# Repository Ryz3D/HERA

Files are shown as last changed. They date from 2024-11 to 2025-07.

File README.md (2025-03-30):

# **HERA**: _**H**opefully **E**lectronics **R**unning **A**utomatically_

A slightly less simple CPU than the [SPEAR](https:#github.com/Ryz3D/SPEAR). It is way more powerful due to:

- Significantly more control lines, thus more instructions
- An extra `C` register
- Direct read and write access to all registers
- Jump and branches as individual instructions (SPEAR solution was creative, but tedious)
- A 16-bit bus (i.e. jump in single cycle)
- 16-bit registers and ALU
- RAM size increased from 256 bytes to 128 KiB
- Additional NOR operation
- Multiple flags (carry out, zero, negative) in a proper status register
- Far better input/output capabilities
- Instructions without literal value fit into one byte

## Features

- Full 16-bit architecture
  - 16-bit addressing for ROM and RAM (ROM: 64 KiB, RAM: 128 KiB)
    - Two RAM chips for direct 16-bit access
  - 16-bit bus, registers and ALU
- Usable digital I/O
  - 256 input ports (16-bit)
  - 256 output ports (16-bit), can be extended at expense of RAM size

## Technical details

### Instructions

The upper 4 bits of any instruction represent control lines for writing to the internal bus (everything but `STAT` uses 16-bit values):
| Upper nibble | Name | Description |
| --- | --- | --- |
| 0 | `LIT` | Literal value |
| 1 | `A` | A register |
| 2 | `B` | B register |
| 3 | `C` | C register |
| 4 | `RAM` | RAM |
| 5 | `RAM_P` | RAM pointer register |
| 6 | `PC` | Program counter register |
| 7 | `STAT`  | Status register (8-bit)  |
| 8 | - | - |
| 9 | - | - |
| A | `ADD` | Add (`A + B`) |
| B | `COM` | Two's complement (`-A`)  |
| C | `NOR` | NOR (`~(A \| B)`) |
| D | - | - |
| E | - | - |
| F | - | - |

If a literal is selected to be written to the bus (upper nibble is 0x0), it is read from the two bytes after the instruction in big-endian format.

The lower 4 bits represent control lines for reading from the internal bus:
| Lower nibble | Name | Description |
| --- | --- | --- |
| 0 | `VOID` | Ignore value |
| 1 | `A` | A register |
| 2 | `B` | B register |
| 3 | `C` | C register |
| 4 | `RAM` | RAM |
| 5 | `RAM_P` | RAM pointer register |
| 6 | `PC` | Program counter register |
| 7 | `STAT` | Status register (8-bit) |
| 8 | - | - |
| 9 | - | - |
| A | `A B` | A & B registers |
| B | `B RAM_P` | B & RAM_P registers |
| C | `C PC` | C & PC registers |
| D | `PC_C` | Program counter if carry flag set |
| E | `PC_Z` | Program counter if zero flag set |
| F | `PC_N` | Program counter if negative flag set |

### Status register

The flags of the status register `STAT` are written on any arithmetic operation (`ADD`, `COM`, `NOR`) and any instruction writing the `A` register. Arithmetic operations overwrite all flags, instructions writing the `A` register overwrite only the zero and negative flags.

| Bit | Description |
| --- | --- |
| 0 (LSB) | Carry (PC_C) |
| 1 | Zero (PC_Z) |
| 2 | Negative (PC_N) |
| 3...8 (MSB) | Reserved |

### Assembly code Examples

### Machine code Examples

Copying the value of the `A` register into the `B` register is done by instruction `0x12` (upper nibble 1 -> write `A` to bus, lower nibble 2 -> read from bus into `B`).

Setting `B` to a literal value is done by instruction `0x02` followed by two bytes in big-endian order (i.e. `0x02 0x12 0x34` -> `B=0x1234`).

Some larger programs showcasing some optimized instructions (all instructions in hexadecimal):

```
# This program writes a lookup-table (array) for showing a 4-bit value as a hexadecimal character on a seven segment display using the following segments (a=LSB, h=MSB):

#  aaa
# f   b
# f   b
# f   b
#  ggg
# e   c
# e   c
# e   c
#  ddd  h

# Using lower nibble 0xB can be a very efficient way to count a pointer (by setting the operand and the pointer in a single instruction), the counting offset (or "step") is determined by the A register.

(00) 01 00 01   # A = 0x01 (increment pointer while writing lookup-table)
(03) 0b 00 80   # B = RAM_P = 0x0080 (base pointer of lookup-table)
(06) 04 00 3f   # Write 0x3f (character '0') at address 0x0080
(09) ab         # Add into B register and RAM_P (increment pointer by 1)
(0A) 04 00 06   # Write 0x06 (character '1') at address 0x0081
(0D) ab         # 
(0E) 04 00 5b   # '2'
(11) ab         # 
(12) 04 00 4f   # '3'
(15) ab         # 
(16) 04 00 66   # '4'
(19) ab         # 
(1A) 04 00 6d   # '5'
(1D) ab         # 
(1E) 04 00 7d   # '6'
(21) ab         # 
(22) 04 00 07   # '7'
(25) ab         # 
(26) 04 00 7f   # '8'
(29) ab         # 
(2A) 04 00 6f   # '9'
(2D) ab         # 
(2E) 04 00 77   # 'A'
(31) ab         # 
(32) 04 00 7c   # 'b'
(35) ab         # 
(36) 04 00 39   # 'C'
(39) ab         # 
(3A) 04 00 5e   # 'd'
(3D) ab         # 
(3E) 04 00 79   # 'E'
(41) ab         # 
(42) 04 00 71   # 'F'

# The following instructions will load the input register and perform a binary AND with 0x000f to get only the lower 4 bits (AND is performed by inverting both inputs to a NOR operation). The result will be added to the base pointer of the lookup-table (0x0080) and the output register will be set to the value at that address to perform the lookup.

(45) 05 01 00   # RAM_P to input register 0x0100
(48) 4a         # Load input into A and B registers to prepare binary NOT
(49) c1         # NOR into A register (NOT of input)
(4A) 02 ff f0   # B = 0xfff0 (NOT of bitmask for lower 4 bits)
(4D) c1         # NOR into A register (AND of input and bitmask)
(4E) 02 00 80   # B = 0x0080 (base pointer of lookup-table)
(51) a5         # Add into RAM_P (pointer to element in lookup-table)
(52) 41         # Load value from lookup-table into A
(53) 05 02 00   # RAM_P to output register 0x0200
(56) 14         # Output A
(57) 06 00 45   # Loop lookup to continuously update (PC = 0x0045)
```

### Default memory map

| Start | End | Description |
| --- | --- | --- |
| ``0x0000`` | ``0x00ff`` | Zeropage |
| ``0x0100`` | ``0x01ff`` | Input registers (default GPIA at 0x0100) |
| ``0x0200`` | ``0x02ff`` | Output registers (default GPOA at 0x0200) |
| ``0x0300`` | ``0x7fff`` | Statically allocated RAM |
| ``0x8004`` | ``0xfbff`` | Dynamically allocated RAM |
| ``0xfc00`` | ``0xffff`` | Stack (starting at 0xffff) |

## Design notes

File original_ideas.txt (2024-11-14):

- Architecture -
16bit (RAM and ROM addresses) -> all buses, all registers, literals!, RAM (two chips parallel for 16bit values, four chips for 16bit addresses)
two 8bit buses -> transfer word by default (both buses), read byte from only low bus
flags: negative, zero, carry
instructions all in one EEPROM. looks like: [INS] [LIT1] [LIT2]
length of an instruction is defined by "write to bus" bits -> zero means literal follows -> proper IR incl. literal

- Software -
intermediate language for large constructs (i.e. function, return, loop), all operations (annotation for keeping/restoring registers), better readability and generalised optimizations
  similar to spear assembly (i.e. "<< -> A")
  incl. 32bit constructs (add LSB, PC_C, add MSB)

- PCB -
SMD ICs, 74HC, maybe ACT (not 260, check availability)
SMD LEDs (bus, registers)
rotary switch -> predefined clock frequencies (0.25 Hz, 1 Hz, 10 Hz, 100 kHz, 2MHz -> 555 limit, could go up to 6MHz)
visible, parallel bus traces (separate high/low buses perhaps)
register: probably xx374, xx16374 does exist but seems expensive
bottom pins like compute module

- Details -
RAM pages:
0x00 zeropage (incl. special addresses)
  0x0011 A register temporary
  0x0012 B register temporary
  0x0013 C register temporary
  0x00FF 16bit stack pointer
0x01 default I (break out 8 decoded lines for simple input devices -> demultiplexer: 2 select bits, all remaining bits zero (NOR) as data input)
0x02 default O (break out 8 decoded lines for simple output devices -> demultiplexer: 2 select bits, all remaining bits zero (NOR) as data input)
0xFE default stack
  0xFEFF - 0xFE00
general purpose outputs can be expanded by an external address decoder/selector at the expense of RAM size
ROM:
0x0000 reset

11/16 write lines:
  0x0 LIT
  0x1 A
  0x2 B
  0x3 C
  0x4 RAM
  0x5 RAM_P
  0x6 PC
  0x7 STAT (byte)
  0x8 reserved (SP (byte))
  0x9 reserved (RAM_P (byte -> zeropage -> RPH pulled down))
  0xA ADD
  0xB COM
  0xC NOR
  0xD reserved
  0xE reserved
  0xF reserved
  (5 remaining)
14/16 read lines:
  0x0 ignore
  0x1 A
  0x2 B
  0x3 C
  0x4 RAM
  0x5 RAM_P
  0x6 PC
  0x7 STAT (byte)
  0x8 reserved (SP (byte))
  0x9 reserved (RAM_P (byte -> zeropage -> RPH pulled down))
  0xA A & B
  0xB B & RAM_P
  0xC C & PC
  0xD PC_C
  0xE PC_Z
  0xF PC_N
  (2 remaining)

    0011
    0101
NOR 1000
AND 0001  (invert inputs -> NOR)
OR  0111  (NOR -> invert)
XOR 0110  (NOR nor AND)

    01
NOT 10    (NOR with itself or literal 0x0000)

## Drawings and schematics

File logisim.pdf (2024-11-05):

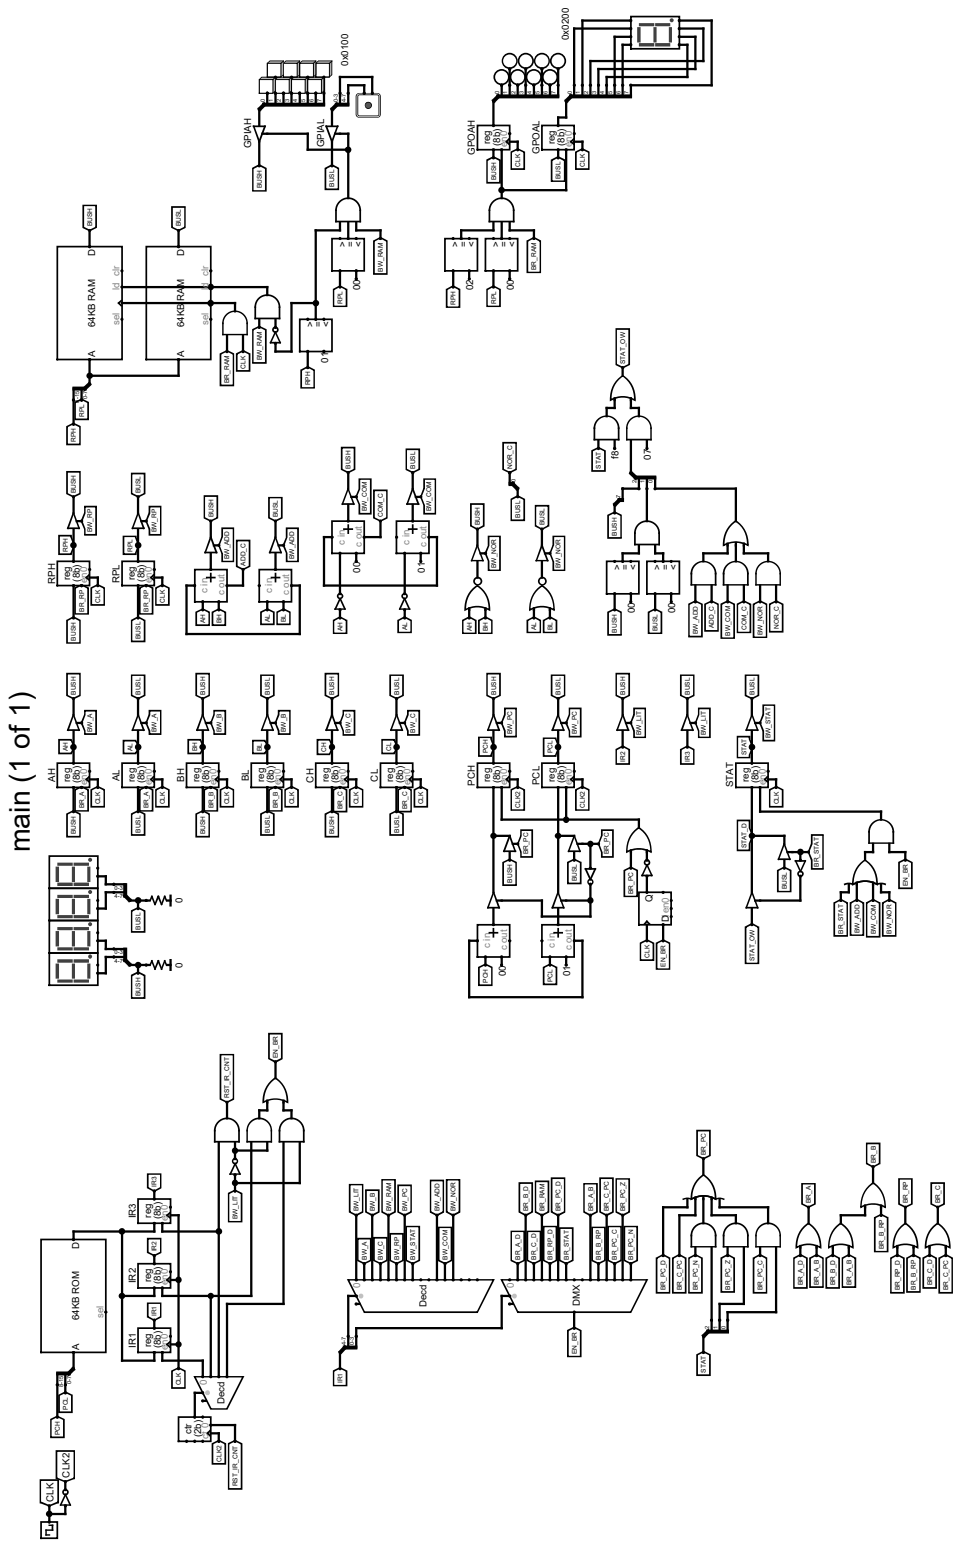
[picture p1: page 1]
0 Decd; < STAT_D IR2 BW_NOR c in c out BR_PC BR_RAM BR_PC_D; CLK; BW_RAM c in c out BUSL; IR¹; 0 enreg (8b⁾ RPH; 0 enreg (8b⁾; NOR_C BUSL; BR_RP_D BUSH; BR_C RPH; 64KB RAM D A; sel ld clr; EN_BR c in c out BUSH; BW_RP PCH; RST_IR_CNT; BUSLCLK; 0 IR3 BUSH BW_RP BW_RAM BW_B AL CLK2 BR_RP_D BR_STAT IR3; 7 BUSL BW_LIT AHBL RST_IR_CNT BR_A_B; 0 1en D Q BUSH AL; BUSL; STAT; < EN_BR CLK 00

0 DMX BR_C BR_PC_D 00 AL0 enreg (8b) BL 0x0200 BUSH BUSH 01 BR_B BR_PC BW_COM GPIAL RPL0 enreg (8b) CLK COM_C

0 BUSL RPL BW_COM BUSH BR_C_PC BR_PC_Z NOR_C BUSL BR_B_D 64KB RAM D A sel ld clr BW_RP RPL BW_COM 00 BR_A_D BR_B_D 0x0100 >

main (1 of 1) 0 ctctr (2b) BR_A CLK CH0 enreg (8b) BW_C STAT0 enreg (8b) 0

0 BUSL 0-3 4-7 CLK BW_A BUSH BW_STAT 8-15 0-7 STAT RPL 4-7 0-3 STAT PCH COM_C IR30 enreg (8b) CL BW_COM BR_A CLK BR_A BL BR_A_B BUSL BW_PC BW_PC 01

7 BUSH BW_B CH BUSL BW_A EN_BR BR_C_D BR_B_RP BW_PC RPH BW_LIT CLK

0 Decd CLK2 c in c out 0 RPL PCL BUSL ADD_C BUSH BR_C BW_C BW_STAT BW_ADD BUSL CLK CLK BW_COM BW_RAM CLK BUSH BR_PC_N BH BW_LIT BW_ADD BR_PC c in c out BR_B BUSL IR20 enreg (8b) BW_NOR AL RPH GPOAH 0 enreg (8b) BR_A_B

< BW_NOR AH BW_ADD BW_LIT BUSL BUSL BW_A BUSH AH0 enreg (8b) BUSH BR_PC BW_B BUSL BUSL BUSL EN_BR BH 00 GPIAH

< GPOAL 0 enreg (8b) BUSL

< STAT_OW CLK BR_A_D IR1 AL BW_ADD BH0 enreg (8b) BR_STAT CLK2 ADD_C PCH0 enreg (8b) BUSH BW_ADD BW_NOR AH 64KB ROM D A sel BUSH BH BUSL BR_C_PC 8-15 0-7 PCL BR_PC_C BL0 enreg (8b) BUSL RPH BUSL BR_RP 00

< IR2 07 STAT_OW BUSH BUSH f8 BR_PC_Z CLK BUSH BR_B CLK BR_RAM BR_STAT c in c out BR_PC_C BR_RP PCL BUSH CLK BW_C CLK2 BR_B_RP BW_NOR 00 02

0 IR10 enreg (8b) PCH BR_RAM BUSH BR_C_DBR_PC_N PCL0 enreg (8b) BR_RP

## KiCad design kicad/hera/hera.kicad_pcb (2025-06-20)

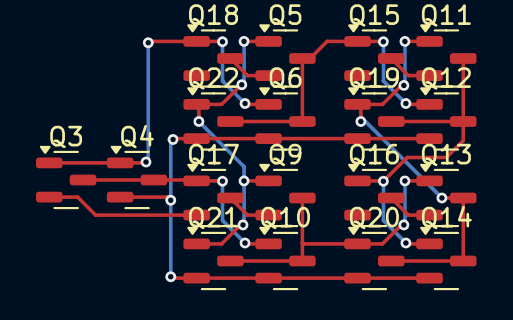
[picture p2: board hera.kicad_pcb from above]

Board: 2 copper layers, 18 parts (0 on the bottom side), 13 nets.

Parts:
Q3, Q5, Q9, Q11, Q13, Q15, Q16, Q17, Q18: BSS84; SOT-23
Q4, Q6, Q10, Q12, Q14, Q19, Q20, Q21, Q22: BSS123; SOT-23

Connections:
/register_1_1/#Q: Q11.1 (G), Q13.3 (D), Q14.3 (D), Q19.1 (G), Q20.3 (D)
/register_1_1/#READ: Q5.1 (G), Q9.1 (G), Q21.1 (G), Q22.1 (G)
/register_1_1/D: Q3.1 (G), Q4.1 (G), Q6.1 (G), Q18.1 (G)
/register_1_1/Q: Q11.3 (D), Q12.3 (D), Q14.1 (G), Q16.1 (G), Q19.3 (D)
/register_1_1/gate_inv_1_1/INV: Q3.3 (D), Q4.3 (D), Q10.1 (G), Q17.1 (G)
/register_1_1/gate_nor_2_1/A: Q5.3 (D), Q6.3 (D), Q12.1 (G), Q15.1 (G), Q22.3 (D)
/register_1_1/gate_nor_2_2/B: Q9.3 (D), Q10.3 (D), Q13.1 (G), Q20.1 (G), Q21.3 (D)
GND: Q4.2 (S), Q6.2 (S), Q10.2 (S), Q12.2 (S), Q14.2 (S), Q19.2 (S), Q20.2 (S), Q21.2 (S), Q22.2 (S)
unnamed: Q11.2 (S), Q15.3 (D)
unnamed: Q13.2 (S), Q16.3 (D)
unnamed: Q9.2 (S), Q17.3 (D)
unnamed: Q5.2 (S), Q18.3 (D)
VDD: Q3.2 (S), Q15.2 (S), Q16.2 (S), Q17.2 (S), Q18.2 (S)

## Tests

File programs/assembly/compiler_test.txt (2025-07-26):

# "main":
(0000) 05 00ff  #  programs/assembly/defaults.ha  l. 132
(0003) 04 ffff  #  programs/assembly/defaults.ha  l. 133
(0006) 01 000c  #  l. 8
(0009) 05 4000  #  l. 9
(000c) 14       #  l. 10
(000d) 05 4000  #  l. 11
(0010) 41       #  l. 12
(0011) 05 00ff  #  programs/assembly/defaults.ha  l. 136
(0014) 45       #  programs/assembly/defaults.ha  l. 137
(0015) 14       #  l. 13
(0016) 05 00ff  #  programs/assembly/defaults.ha  l. 139
(0019) 42       #  programs/assembly/defaults.ha  l. 64
(001a) 01 ffff  #  programs/assembly/defaults.ha  l. 65
(001d) a4       #  programs/assembly/defaults.ha  l. 66
(001e) 05 00ff  #  programs/assembly/defaults.ha  l. 143
(0021) 42       #  programs/assembly/defaults.ha  l. 59
(0022) 01 0001  #  programs/assembly/defaults.ha  l. 60
(0025) a4       #  programs/assembly/defaults.ha  l. 61
(0026) 45       #  programs/assembly/defaults.ha  l. 145
(0027) 41       #  programs/assembly/defaults.ha  l. 146
(0028) 05 4002  #  l. 15
(002b) 14       #  l. 16
(002c) 05 4002  #  l. 17
(002f) 41       #  l. 18
(0030) 05 00ff  #  programs/assembly/defaults.ha  l. 136
(0033) 45       #  programs/assembly/defaults.ha  l. 137
(0034) 14       #  l. 19
(0035) 05 00ff  #  programs/assembly/defaults.ha  l. 139
(0038) 42       #  programs/assembly/defaults.ha  l. 64
(0039) 01 ffff  #  programs/assembly/defaults.ha  l. 65
(003c) a4       #  programs/assembly/defaults.ha  l. 66
(003d) 05 00ff  #  programs/assembly/defaults.ha  l. 143
(0040) 42       #  programs/assembly/defaults.ha  l. 59
(0041) 01 0001  #  programs/assembly/defaults.ha  l. 60
(0044) a4       #  programs/assembly/defaults.ha  l. 61
(0045) 45       #  programs/assembly/defaults.ha  l. 145
(0046) 41       #  programs/assembly/defaults.ha  l. 146
(0047) 02 ffff  #  l. 21
(004a) a1       #  l. 22
(004b) 05 4001  #  l. 23
(004e) 14       #  l. 24
(004f) 05 4001  #  l. 25
(0052) 41       #  l. 26
(0053) 05 00ff  #  programs/assembly/defaults.ha  l. 136
(0056) 45       #  programs/assembly/defaults.ha  l. 137
(0057) 14       #  l. 27
(0058) 05 00ff  #  programs/assembly/defaults.ha  l. 139
(005b) 42       #  programs/assembly/defaults.ha  l. 64
(005c) 01 ffff  #  programs/assembly/defaults.ha  l. 65
(005f) a4       #  programs/assembly/defaults.ha  l. 66
(0060) 05 00ff  #  programs/assembly/defaults.ha  l. 143
(0063) 42       #  programs/assembly/defaults.ha  l. 59
(0064) 01 0001  #  programs/assembly/defaults.ha  l. 60
(0067) a4       #  programs/assembly/defaults.ha  l. 61
(0068) 45       #  programs/assembly/defaults.ha  l. 145
(0069) 41       #  programs/assembly/defaults.ha  l. 146
(006a) 05 4001  #  l. 29
(006d) 14       #  l. 30
(006e) 01 65eb  #  l. 32
(0071) 05 4000  #  l. 33
(0074) 14       #  l. 34
(0075) 05 4000  #  l. 35
(0078) 41       #  l. 36
(0079) 05 00ff  #  programs/assembly/defaults.ha  l. 136
(007c) 45       #  programs/assembly/defaults.ha  l. 137
(007d) 14       #  l. 37
(007e) 05 00ff  #  programs/assembly/defaults.ha  l. 139
(0081) 42       #  programs/assembly/defaults.ha  l. 64
(0082) 01 ffff  #  programs/assembly/defaults.ha  l. 65
(0085) a4       #  programs/assembly/defaults.ha  l. 66
(0086) 05 00ff  #  programs/assembly/defaults.ha  l. 143
(0089) 42       #  programs/assembly/defaults.ha  l. 59
(008a) 01 0001  #  programs/assembly/defaults.ha  l. 60
(008d) a4       #  programs/assembly/defaults.ha  l. 61
(008e) 45       #  programs/assembly/defaults.ha  l. 145
(008f) 41       #  programs/assembly/defaults.ha  l. 146
(0090) 05 4003  #  l. 39
(0093) 14       #  l. 40
(0094) 05 4003  #  l. 42
(0097) 41       #  l. 43
(0098) 05 00ff  #  programs/assembly/defaults.ha  l. 136
(009b) 45       #  programs/assembly/defaults.ha  l. 137
(009c) 14       #  l. 44
(009d) 05 00ff  #  programs/assembly/defaults.ha  l. 139
(00a0) 42       #  programs/assembly/defaults.ha  l. 64
(00a1) 01 ffff  #  programs/assembly/defaults.ha  l. 65
(00a4) a4       #  programs/assembly/defaults.ha  l. 66
(00a5) 05 00ff  #  programs/assembly/defaults.ha  l. 143
(00a8) 42       #  programs/assembly/defaults.ha  l. 59
(00a9) 01 0001  #  programs/assembly/defaults.ha  l. 60
(00ac) a4       #  programs/assembly/defaults.ha  l. 61
(00ad) 45       #  programs/assembly/defaults.ha  l. 145
(00ae) 41       #  programs/assembly/defaults.ha  l. 146
(00af) 05 4001  #  l. 46
(00b2) 14       #  l. 47
(00b3) 05 4001  #  l. 48
(00b6) 41       #  l. 49
(00b7) 05 00ff  #  programs/assembly/defaults.ha  l. 136
(00ba) 45       #  programs/assembly/defaults.ha  l. 137
(00bb) 14       #  l. 50
(00bc) 05 00ff  #  programs/assembly/defaults.ha  l. 139
(00bf) 42       #  programs/assembly/defaults.ha  l. 64
(00c0) 01 ffff  #  programs/assembly/defaults.ha  l. 65
(00c3) a4       #  programs/assembly/defaults.ha  l. 66
(00c4) 05 00ff  #  programs/assembly/defaults.ha  l. 143
(00c7) 42       #  programs/assembly/defaults.ha  l. 59
(00c8) 01 0001  #  programs/assembly/defaults.ha  l. 60
(00cb) a4       #  programs/assembly/defaults.ha  l. 61
(00cc) 45       #  programs/assembly/defaults.ha  l. 145
(00cd) 41       #  programs/assembly/defaults.ha  l. 146
(00ce) 05 4004  #  l. 52
(00d1) 14       #  l. 53
(00d2) 05 4004  #  l. 55
(00d5) 41       #  l. 56
(00d6) 05 00ff  #  programs/assembly/defaults.ha  l. 136
(00d9) 45       #  programs/assembly/defaults.ha  l. 137
(00da) 14       #  l. 57
(00db) 05 00ff  #  programs/assembly/defaults.ha  l. 139
(00de) 42       #  programs/assembly/defaults.ha  l. 64
(00df) 01 ffff  #  programs/assembly/defaults.ha  l. 65
(00e2) a4       #  programs/assembly/defaults.ha  l. 66
(00e3) 05 00ff  #  programs/assembly/defaults.ha  l. 143
(00e6) 42       #  programs/assembly/defaults.ha  l. 59
(00e7) 01 0001  #  programs/assembly/defaults.ha  l. 60
(00ea) a4       #  programs/assembly/defaults.ha  l. 61
(00eb) 45       #  programs/assembly/defaults.ha  l. 145
(00ec) 41       #  programs/assembly/defaults.ha  l. 146
(00ed) 05 4001  #  l. 59
(00f0) 14       #  l. 60
(00f1) 05 4001  #  l. 61
(00f4) 41       #  l. 62
(00f5) 05 00ff  #  programs/assembly/defaults.ha  l. 136
(00f8) 45       #  programs/assembly/defaults.ha  l. 137
(00f9) 14       #  l. 63
(00fa) 05 00ff  #  programs/assembly/defaults.ha  l. 139
(00fd) 42       #  programs/assembly/defaults.ha  l. 64
(00fe) 01 ffff  #  programs/assembly/defaults.ha  l. 65
(0101) a4       #  programs/assembly/defaults.ha  l. 66
(0102) 05 00ff  #  programs/assembly/defaults.ha  l. 143
(0105) 42       #  programs/assembly/defaults.ha  l. 59
(0106) 01 0001  #  programs/assembly/defaults.ha  l. 60
(0109) a4       #  programs/assembly/defaults.ha  l. 61
(010a) 45       #  programs/assembly/defaults.ha  l. 145
(010b) 41       #  programs/assembly/defaults.ha  l. 146
(010c) 05 4005  #  l. 65
(010f) 14       #  l. 66
(0110) 01 0001  #  l. 67
(0113) 05 4000  #  l. 68
(0116) 14       #  l. 69
(0117) 05 4000  #  l. 70
(011a) 41       #  l. 71
(011b) 05 00ff  #  programs/assembly/defaults.ha  l. 136
(011e) 45       #  programs/assembly/defaults.ha  l. 137
(011f) 14       #  l. 72
(0120) 05 00ff  #  programs/assembly/defaults.ha  l. 139
(0123) 42       #  programs/assembly/defaults.ha  l. 64
(0124) 01 ffff  #  programs/assembly/defaults.ha  l. 65
(0127) a4       #  programs/assembly/defaults.ha  l. 66
(0128) 05 4003  #  l. 73
(012b) 41       #  l. 74
(012c) 05 00ff  #  programs/assembly/defaults.ha  l. 136
(012f) 45       #  programs/assembly/defaults.ha  l. 137
(0130) 14       #  l. 75
(0131) 05 00ff  #  programs/assembly/defaults.ha  l. 139
(0134) 42       #  programs/assembly/defaults.ha  l. 64
(0135) 01 ffff  #  programs/assembly/defaults.ha  l. 65
(0138) a4       #  programs/assembly/defaults.ha  l. 66
(0139) 05 00ff  #  programs/assembly/defaults.ha  l. 143
(013c) 42       #  programs/assembly/defaults.ha  l. 59
(013d) 01 0001  #  programs/assembly/defaults.ha  l. 60
(0140) a4       #  programs/assembly/defaults.ha  l. 61
(0141) 45       #  programs/assembly/defaults.ha  l. 145
(0142) 41       #  programs/assembly/defaults.ha  l. 146
(0143) 05 0011  #  l. 1
(0146) 14       #  l. 1
(0147) 05 00ff  #  programs/assembly/defaults.ha  l. 143
(014a) 42       #  programs/assembly/defaults.ha  l. 59
(014b) 01 0001  #  programs/assembly/defaults.ha  l. 60
(014e) a4       #  programs/assembly/defaults.ha  l. 61
(014f) 45       #  programs/assembly/defaults.ha  l. 145
(0150) 42       #  programs/assembly/defaults.ha  l. 146
(0151) 05 0011  #  l. 1
(0154) 41       #  l. 1
(0155) 13       #  programs/assembly/defaults.ha  l. 87
(0156) 21       #  programs/assembly/defaults.ha  l. 88
(0157) b2       #  programs/assembly/defaults.ha  l. 89
(0158) 31       #  programs/assembly/defaults.ha  l. 90
(0159) a1       #  programs/assembly/defaults.ha  l. 91
(015a) 05 4001  #  l. 79
(015d) 14       #  l. 80
(015e) 05 4001  #  l. 81
(0161) 41       #  l. 82
(0162) 05 00ff  #  programs/assembly/defaults.ha  l. 136
(0165) 45       #  programs/assembly/defaults.ha  l. 137
(0166) 14       #  l. 83
(0167) 05 00ff  #  programs/assembly/defaults.ha  l. 139
(016a) 42       #  programs/assembly/defaults.ha  l. 64
(016b) 01 ffff  #  programs/assembly/defaults.ha  l. 65
(016e) a4       #  programs/assembly/defaults.ha  l. 66
(016f) 01 0002  #  l. 84
(0172) 05 4000  #  l. 85
(0175) 14       #  l. 86
(0176) 05 4000  #  l. 87
(0179) 41       #  l. 88
(017a) 05 00ff  #  programs/assembly/defaults.ha  l. 136
(017d) 45       #  programs/assembly/defaults.ha  l. 137
(017e) 14       #  l. 89
(017f) 05 00ff  #  programs/assembly/defaults.ha  l. 139
(0182) 42       #  programs/assembly/defaults.ha  l. 64
(0183) 01 ffff  #  programs/assembly/defaults.ha  l. 65
(0186) a4       #  programs/assembly/defaults.ha  l. 66
(0187) 05 00ff  #  programs/assembly/defaults.ha  l. 143
(018a) 42       #  programs/assembly/defaults.ha  l. 59
(018b) 01 0001  #  programs/assembly/defaults.ha  l. 60
(018e) a4       #  programs/assembly/defaults.ha  l. 61
(018f) 45       #  programs/assembly/defaults.ha  l. 145
(0190) 41       #  programs/assembly/defaults.ha  l. 146
(0191) 05 0011  #  l. 1
(0194) 14       #  l. 1
(0195) 05 00ff  #  programs/assembly/defaults.ha  l. 143
(0198) 42       #  programs/assembly/defaults.ha  l. 59
(0199) 01 0001  #  programs/assembly/defaults.ha  l. 60
(019c) a4       #  programs/assembly/defaults.ha  l. 61
(019d) 45       #  programs/assembly/defaults.ha  l. 145
(019e) 42       #  programs/assembly/defaults.ha  l. 146
(019f) 05 0011  #  l. 1
(01a2) 41       #  l. 1
(01a3) 21       #  l. 92
(01a4) a1       #  l. 93
(01a5) 05 4001  #  l. 94
(01a8) 14       #  l. 95
(01a9) 05 4001  #  l. 96
(01ac) 41       #  l. 97
(01ad) 05 00ff  #  programs/assembly/defaults.ha  l. 136
(01b0) 45       #  programs/assembly/defaults.ha  l. 137
(01b1) 14       #  l. 98
(01b2) 05 00ff  #  programs/assembly/defaults.ha  l. 139
(01b5) 42       #  programs/assembly/defaults.ha  l. 64
(01b6) 01 ffff  #  programs/assembly/defaults.ha  l. 65
(01b9) a4       #  programs/assembly/defaults.ha  l. 66
(01ba) 01 0004  #  l. 99
(01bd) 05 4000  #  l. 100
(01c0) 14       #  l. 101
(01c1) 05 4000  #  l. 102
(01c4) 41       #  l. 103
(01c5) 05 00ff  #  programs/assembly/defaults.ha  l. 136
(01c8) 45       #  programs/assembly/defaults.ha  l. 137
(01c9) 14       #  l. 104
(01ca) 05 00ff  #  programs/assembly/defaults.ha  l. 139
(01cd) 42       #  programs/assembly/defaults.ha  l. 64
(01ce) 01 ffff  #  programs/assembly/defaults.ha  l. 65
(01d1) a4       #  programs/assembly/defaults.ha  l. 66
(01d2) 05 00ff  #  programs/assembly/defaults.ha  l. 143
(01d5) 42       #  programs/assembly/defaults.ha  l. 59
(01d6) 01 0001  #  programs/assembly/defaults.ha  l. 60
(01d9) a4       #  programs/assembly/defaults.ha  l. 61
(01da) 45       #  programs/assembly/defaults.ha  l. 145
(01db) 41       #  programs/assembly/defaults.ha  l. 146
(01dc) 05 0011  #  l. 1
(01df) 14       #  l. 1
(01e0) 05 00ff  #  programs/assembly/defaults.ha  l. 143
(01e3) 42       #  programs/assembly/defaults.ha  l. 59
(01e4) 01 0001  #  programs/assembly/defaults.ha  l. 60
(01e7) a4       #  programs/assembly/defaults.ha  l. 61
(01e8) 45       #  programs/assembly/defaults.ha  l. 145
(01e9) 42       #  programs/assembly/defaults.ha  l. 146
(01ea) 05 0011  #  l. 1
(01ed) 41       #  l. 1
(01ee) 05 0011  #  l. 1
(01f1) 14       #  l. 1
(01f2) 05 0012  #  l. 1
(01f5) 24       #  l. 1
(01f6) 05 0012  #  programs/assembly/defaults.ha  l. 15
(01f9) 24       #  programs/assembly/defaults.ha  l. 16
(01fa) 12       #  programs/assembly/defaults.ha  l. 109
(01fb) c3       #  programs/assembly/defaults.ha  l. 110
(01fc) 05 0012  #  programs/assembly/defaults.ha  l. 19
(01ff) 42       #  programs/assembly/defaults.ha  l. 20
(0200) 21       #  programs/assembly/defaults.ha  l. 112
(0201) c2       #  programs/assembly/defaults.ha  l. 113
(0202) 31       #  programs/assembly/defaults.ha  l. 114
(0203) c3       #  programs/assembly/defaults.ha  l. 115
(0204) 05 0011  #  l. 1
(0207) 41       #  l. 1
(0208) 05 0012  #  l. 1
(020b) 42       #  l. 1
(020c) c1       #  programs/assembly/defaults.ha  l. 119
(020d) 32       #  programs/assembly/defaults.ha  l. 120
(020e) c1       #  programs/assembly/defaults.ha  l. 121
(020f) 05 4001  #  l. 108
(0212) 14       #  l. 109
(0213) 05 4001  #  l. 110
(0216) 41       #  l. 111
(0217) 05 00ff  #  programs/assembly/defaults.ha  l. 136
(021a) 45       #  programs/assembly/defaults.ha  l. 137
(021b) 14       #  l. 112
(021c) 05 00ff  #  programs/assembly/defaults.ha  l. 139
(021f) 42       #  programs/assembly/defaults.ha  l. 64
(0220) 01 ffff  #  programs/assembly/defaults.ha  l. 65
(0223) a4       #  programs/assembly/defaults.ha  l. 66
(0224) 05 4005  #  l. 113
(0227) 41       #  l. 114
(0228) 05 00ff  #  programs/assembly/defaults.ha  l. 136
(022b) 45       #  programs/assembly/defaults.ha  l. 137
(022c) 14       #  l. 115
(022d) 05 00ff  #  programs/assembly/defaults.ha  l. 139
(0230) 42       #  programs/assembly/defaults.ha  l. 64
(0231) 01 ffff  #  programs/assembly/defaults.ha  l. 65
(0234) a4       #  programs/assembly/defaults.ha  l. 66
(0235) 05 00ff  #  programs/assembly/defaults.ha  l. 143
(0238) 42       #  programs/assembly/defaults.ha  l. 59
(0239) 01 0001  #  programs/assembly/defaults.ha  l. 60
(023c) a4       #  programs/assembly/defaults.ha  l. 61
(023d) 45       #  programs/assembly/defaults.ha  l. 145
(023e) 41       #  programs/assembly/defaults.ha  l. 146
(023f) 05 0011  #  l. 1
(0242) 14       #  l. 1
(0243) 05 00ff  #  programs/assembly/defaults.ha  l. 143
(0246) 42       #  programs/assembly/defaults.ha  l. 59
(0247) 01 0001  #  programs/assembly/defaults.ha  l. 60
(024a) a4       #  programs/assembly/defaults.ha  l. 61
(024b) 45       #  programs/assembly/defaults.ha  l. 145
(024c) 42       #  programs/assembly/defaults.ha  l. 146
(024d) 05 0011  #  l. 1
(0250) 41       #  l. 1
(0251) 05 4001  #  l. 118
(0254) 14       #  l. 119
(0255) 05 4001  #  l. 120
(0258) 41       #  l. 121
(0259) 05 00ff  #  programs/assembly/defaults.ha  l. 136
(025c) 45       #  programs/assembly/defaults.ha  l. 137
(025d) 14       #  l. 122
(025e) 05 00ff  #  programs/assembly/defaults.ha  l. 139
(0261) 42       #  programs/assembly/defaults.ha  l. 64
(0262) 01 ffff  #  programs/assembly/defaults.ha  l. 65
(0265) a4       #  programs/assembly/defaults.ha  l. 66
(0266) 05 00ff  #  programs/assembly/defaults.ha  l. 143
(0269) 42       #  programs/assembly/defaults.ha  l. 59
(026a) 01 0001  #  programs/assembly/defaults.ha  l. 60
(026d) a4       #  programs/assembly/defaults.ha  l. 61
(026e) 45       #  programs/assembly/defaults.ha  l. 145
(026f) 41       #  programs/assembly/defaults.ha  l. 146
(0270) 05 4001  #  l. 124
(0273) 14       #  l. 125
(0274) 05 4005  #  l. 126
(0277) 41       #  l. 127
(0278) 05 00ff  #  programs/assembly/defaults.ha  l. 136
(027b) 45       #  programs/assembly/defaults.ha  l. 137
(027c) 14       #  l. 128
(027d) 05 00ff  #  programs/assembly/defaults.ha  l. 139
(0280) 42       #  programs/assembly/defaults.ha  l. 64
(0281) 01 ffff  #  programs/assembly/defaults.ha  l. 65
(0284) a4       #  programs/assembly/defaults.ha  l. 66
(0285) 05 00ff  #  programs/assembly/defaults.ha  l. 143
(0288) 42       #  programs/assembly/defaults.ha  l. 59
(0289) 01 0001  #  programs/assembly/defaults.ha  l. 60
(028c) a4       #  programs/assembly/defaults.ha  l. 61
(028d) 45       #  programs/assembly/defaults.ha  l. 145
(028e) 41       #  programs/assembly/defaults.ha  l. 146
(028f) 05 4001  #  l. 130
(0292) 14       #  l. 131
(0293) 01 0025  #  l. 132
(0296) 05 4000  #  l. 133
(0299) 14       #  l. 134
(029a) 05 4000  #  l. 135
(029d) 41       #  l. 136
(029e) 05 00ff  #  programs/assembly/defaults.ha  l. 136
(02a1) 45       #  programs/assembly/defaults.ha  l. 137
(02a2) 14       #  l. 137
(02a3) 05 00ff  #  programs/assembly/defaults.ha  l. 139
(02a6) 42       #  programs/assembly/defaults.ha  l. 64
(02a7) 01 ffff  #  programs/assembly/defaults.ha  l. 65
(02aa) a4       #  programs/assembly/defaults.ha  l. 66
(02ab) 05 4005  #  l. 138
(02ae) 41       #  l. 139
(02af) 05 00ff  #  programs/assembly/defaults.ha  l. 136
(02b2) 45       #  programs/assembly/defaults.ha  l. 137
(02b3) 14       #  l. 140
(02b4) 05 00ff  #  programs/assembly/defaults.ha  l. 139
(02b7) 42       #  programs/assembly/defaults.ha  l. 64
(02b8) 01 ffff  #  programs/assembly/defaults.ha  l. 65
(02bb) a4       #  programs/assembly/defaults.ha  l. 66
(02bc) 05 00ff  #  programs/assembly/defaults.ha  l. 143
(02bf) 42       #  programs/assembly/defaults.ha  l. 59
(02c0) 01 0001  #  programs/assembly/defaults.ha  l. 60
(02c3) a4       #  programs/assembly/defaults.ha  l. 61
(02c4) 45       #  programs/assembly/defaults.ha  l. 145
(02c5) 41       #  programs/assembly/defaults.ha  l. 146
(02c6) 05 4001  #  l. 142
(02c9) 14       #  l. 143
(02ca) 01 0000  #  l. 144
(02cd) 05 4000  #  l. 145
(02d0) 14       #  l. 146
(02d1) 05 4000  #  l. 147
(02d4) 41       #  l. 148
(02d5) 05 00ff  #  programs/assembly/defaults.ha  l. 136
(02d8) 45       #  programs/assembly/defaults.ha  l. 137
(02d9) 14       #  l. 149
(02da) 05 00ff  #  programs/assembly/defaults.ha  l. 139
(02dd) 42       #  programs/assembly/defaults.ha  l. 64
(02de) 01 ffff  #  programs/assembly/defaults.ha  l. 65
(02e1) a4       #  programs/assembly/defaults.ha  l. 66
# "end":
(02e2) 06 02e2  #  l. 151

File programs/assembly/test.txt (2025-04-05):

# "main":
(0000) 05 00ff  #  programs/assembly/defaults.ha  l. 132
(0003) 04 ffff  #  programs/assembly/defaults.ha  l. 133
(0006) 01 0001  #  programs/assembly/malloc.ha  l. 15
(0009) 0b 8000  #  programs/assembly/malloc.ha  l. 16
(000c) 04 0000  #  programs/assembly/malloc.ha  l. 16
(000f) ab       #  programs/assembly/malloc.ha  l. 17
(0010) 04 0000  #  programs/assembly/malloc.ha  l. 17
(0013) ab       #  programs/assembly/malloc.ha  l. 18
(0014) 04 7bfc  #  programs/assembly/malloc.ha  l. 18
(0017) ab       #  programs/assembly/malloc.ha  l. 19
(0018) 04 0000  #  programs/assembly/malloc.ha  l. 19
(001b) 01 0010  #  l. 8
(001e) 05 0011  #  programs/assembly/defaults.ha  l. 7
(0021) 14       #  programs/assembly/defaults.ha  l. 8
(0022) 61       #  programs/assembly/defaults.ha  l. 154
(0023) 02 0013  #  programs/assembly/defaults.ha  l. 155
(0026) 05 00ff  #  programs/assembly/defaults.ha  l. 136
(0029) 45       #  programs/assembly/defaults.ha  l. 137
(002a) a4       #  programs/assembly/defaults.ha  l. 156
(002b) 05 00ff  #  programs/assembly/defaults.ha  l. 139
(002e) 42       #  programs/assembly/defaults.ha  l. 64
(002f) 01 ffff  #  programs/assembly/defaults.ha  l. 65
(0032) a4       #  programs/assembly/defaults.ha  l. 66
(0033) 06 0091  #  l. 10
(0036) 05 0200  #  programs/assembly/defaults.ha  l. 73
(0039) 14       #  l. 11
(003a) 05 1000  #  l. 12
(003d) 14       #  l. 13
(003e) 01 0001  #  l. 15
(0041) 05 1000  #  l. 16
(0044) 4b       #  l. 17
(0045) 04 1234  #  l. 17
(0048) ab       #  l. 18
(0049) 04 5678  #  l. 18
(004c) ab       #  l. 19
(004d) 04 9abc  #  l. 19
(0050) ab       #  l. 20
(0051) 04 def0  #  l. 20
(0054) 01 0001  #  l. 22
(0057) 05 1000  #  l. 23
(005a) 4b       #  l. 24
(005b) 43       #  l. 24
(005c) 05 0200  #  programs/assembly/defaults.ha  l. 73
(005f) 34       #  l. 24
(0060) ab       #  l. 25
(0061) 43       #  l. 25
(0062) 05 0200  #  programs/assembly/defaults.ha  l. 73
(0065) 34       #  l. 25
(0066) ab       #  l. 26
(0067) 43       #  l. 26
(0068) 05 0200  #  programs/assembly/defaults.ha  l. 73
(006b) 34       #  l. 26
(006c) ab       #  l. 27
(006d) 43       #  l. 27
(006e) 05 0200  #  programs/assembly/defaults.ha  l. 73
(0071) 34       #  l. 27
(0072) 05 1000  #  l. 29
(0075) 41       #  l. 30
(0076) 05 0011  #  programs/assembly/defaults.ha  l. 7
(0079) 14       #  programs/assembly/defaults.ha  l. 8
(007a) 61       #  programs/assembly/defaults.ha  l. 154
(007b) 02 0013  #  programs/assembly/defaults.ha  l. 155
(007e) 05 00ff  #  programs/assembly/defaults.ha  l. 136
(0081) 45       #  programs/assembly/defaults.ha  l. 137
(0082) a4       #  programs/assembly/defaults.ha  l. 156
(0083) 05 00ff  #  programs/assembly/defaults.ha  l. 139
(0086) 42       #  programs/assembly/defaults.ha  l. 64
(0087) 01 ffff  #  programs/assembly/defaults.ha  l. 65
(008a) a4       #  programs/assembly/defaults.ha  l. 66
(008b) 06 00d2  #  l. 32
# "end":
(008e) 06 008e  #  l. 35
# "malloc":
(0091) 05 0011  #  programs/assembly/defaults.ha  l. 11
(0094) 41       #  programs/assembly/defaults.ha  l. 12
(0095) 05 0040  #  programs/assembly/malloc.ha  l. 24
(0098) 14       #  programs/assembly/malloc.ha  l. 25
(0099) 05 0041  #  programs/assembly/malloc.ha  l. 27
(009c) 04 8000  #  programs/assembly/malloc.ha  l. 28
# "malloc_loop_find_block":
(009f) 05 0041  #  programs/assembly/malloc.ha  l. 31
(00a2) 41       #  programs/assembly/malloc.ha  l. 32
(00a3) 0e 00ba  #  programs/assembly/malloc.ha  l. 33
(00a6) 05 0041  #  programs/assembly/malloc.ha  l. 38
(00a9) 41       #  programs/assembly/malloc.ha  l. 39
(00aa) 02 0001  #  programs/assembly/malloc.ha  l. 40
(00ad) a5       #  programs/assembly/malloc.ha  l. 41
(00ae) 41       #  programs/assembly/malloc.ha  l. 42
(00af) 05 0041  #  programs/assembly/malloc.ha  l. 43
(00b2) 14       #  programs/assembly/malloc.ha  l. 44
(00b3) 06 009f  #  programs/assembly/malloc.ha  l. 45
(00b6) 05 0011  #  programs/assembly/defaults.ha  l. 11
(00b9) 41       #  programs/assembly/defaults.ha  l. 12
# "malloc_return_null":
(00ba) 01 0000  #  programs/assembly/malloc.ha  l. 50
(00bd) 05 0011  #  l. 1
(00c0) 14       #  l. 1
(00c1) 05 00ff  #  programs/assembly/defaults.ha  l. 161
(00c4) 42       #  programs/assembly/defaults.ha  l. 59
(00c5) 01 0001  #  programs/assembly/defaults.ha  l. 60
(00c8) a4       #  programs/assembly/defaults.ha  l. 61
(00c9) 05 0011  #  l. 1
(00cc) 41       #  l. 1
(00cd) 05 00ff  #  programs/assembly/defaults.ha  l. 164
(00d0) 45       #  programs/assembly/defaults.ha  l. 165
(00d1) 46       #  programs/assembly/defaults.ha  l. 166
# "mfree":
(00d2) 05 0011  #  programs/assembly/defaults.ha  l. 11
(00d5) 41       #  programs/assembly/defaults.ha  l. 12
(00d6) 05 00ff  #  programs/assembly/defaults.ha  l. 161
(00d9) 42       #  programs/assembly/defaults.ha  l. 59
(00da) 01 0001  #  programs/assembly/defaults.ha  l. 60
(00dd) a4       #  programs/assembly/defaults.ha  l. 61
(00de) 05 00ff  #  programs/assembly/defaults.ha  l. 164
(00e1) 45       #  programs/assembly/defaults.ha  l. 165
(00e2) 46       #  programs/assembly/defaults.ha  l. 166

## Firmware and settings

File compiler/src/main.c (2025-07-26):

#include "includes.h"

int main(int argc, char *argv[]) {
    const char *path_src = NULL;
#if DEBUG
    path_src = DEBUG_SRC;
#else
    if (argc > 1) {
        path_src = argv[1];
    } else {
        printf(ERROR "specify source file as argument" ENDL);

        printf(NOK ENDL);
        return 1;
    }
#endif

    inter_ins_t *inter_ins;
    uint32_t inter_ins_count;
    if (!cmp_parser_run(path_src, &inter_ins, &inter_ins_count)) {
        free(inter_ins);

        printf(NOK ENDL);
        return 1;
    }

    asm_ins_t *asm_ins;
    uint32_t asm_ins_count;
    if (!cmp_asm_generate(inter_ins, inter_ins_count, &asm_ins, &asm_ins_count)) {
        free(inter_ins);
        free(asm_ins);

        printf(NOK ENDL);
        return 1;
    }

    cmp_inter_debug_print(inter_ins, inter_ins_count);
    printf(ENDL);
    cmp_asm_debug_print(asm_ins, asm_ins_count);
    printf(ENDL);
    cmp_inter_debug_sim(inter_ins, inter_ins_count);

    free(inter_ins);

    /*
    TODO:
    - optimize
     - simulate intermediate program, save known state, reset on label
     - remove unused variables
    - output
     - based on file extension of specified output path
      - (tokens)
      - (inter)
      - (hera asm)
      - (hera bin)
    */

    if (!cmp_asm_write("./programs/assembly/compiler_test.ha", asm_ins, asm_ins_count)) {
        free(asm_ins);

        printf(NOK ENDL);
        return 1;
    }
    free(asm_ins);

    printf(OK ENDL);
    return 0;
}

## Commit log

2024-11-02 changed control word, started logisim circuit
2024-11-02 simulation mostly running, interrupts missing
2024-11-04 simulation running well, start of assembler
2024-11-14 progress on assembler and assembly language
2025-01-22 initial python simulator and c assembler
2025-01-22 initial AST parser for assembler
2025-01-25 fixed mistaken current_token
2025-03-14 first binary output from assembler. missing defs
2025-03-25 simulator no longer interactive, now for assembly debugging
2025-03-30 fixed assembler freeing bug
2025-04-15 prepared structure for data flow: tokenizer -> parser -> intermediate -> asm
2025-04-26 token error messages, bracket checker
    [main.c]
2025-06-20 logisim logic gate implementation, parser progress
    [adder_1.kicad_sch, adder_16.kicad_sch, decoder_2.kicad_sch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]
2025-06-26 extended intermediate language, simple assembly file output structure
